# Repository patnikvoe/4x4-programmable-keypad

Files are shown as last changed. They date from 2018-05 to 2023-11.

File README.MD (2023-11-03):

# 4x4 Programmable Keyboard
This project allows you to make a 4x4 programmable keypad. Its similar to standalone numpads, however you can programm each key individually to press one key, key combinations or even complex macros.

## Materials needed:
* 6 mm x 6 mm Tacticle Button (16x)
* 51k Resistor 0603 (16x)
* USB Micro Cable (1x)
* Sparkfun Pro Micro (5V or 3.3V shouldn't really matter) (1x)
* PCB milled with eagle files provided or perfboard + wiring cables
* 3D Printed Enclosure for looks (1x)
* screws depending on your enclosure design 

## Files
All files are stored in there respective folder. Code contains the C++ code for the Sparkfun Pro Micro. Eagle contains the Schematic and Board Files for the ECAD software "Autodesk Eagle".
### Code
The code was written and uploaded using the [hackable texteditor Atom](https://atom.io/) and the extentions [PlatformIO](https://platformio.org/platformio-ide), which are both available for Windows, Linux and macOS.

If you want to use the Arduino IDE, you need to perform two little changes.
Delete the following line or comment it out in the file `code/src/4x4-programmable-keypad.cpp` (Line 7).
```cpp
#include <Arduino.h>
```
Change the File name to `code/src/4x4-programmable-keypad.ino`.

### Quick start in programming your keys
Check the [Arduino Reference](https://www.arduino.cc/reference/en/language/functions/usb/keyboard/) for more detailed information.
#### Keyboard.press(), Keyboard.release(), Keyboard.releaseAll()
Press and release a single keys
```cpp
Keyboard.press(ALT);    // press the left ALT key
delay(50);              // Delays for 50 ms, you might be able to go lower, but 50 is a good starting point
Keyboard.release(ALT);  // Releases the left ALT key again; Alternatively Keyboard.releaseAll()
delay(200);             // Delay for 200 ms so it doesn't get run twice
```
Press and release a key combination
```cpp
Keyboard.press(STRG);   // press the left CTRL/STRG key
Keyboard.press('c');    // press the "c" key
delay(50);
Keyboard.releaseAll();  // release all keys
delay(200);
```
Press and release in a loop to repeat a set number of times
```cpp
for (int i=0;i<10;++i){   // repeat the key combination 10 times
  Keyboard.press(STRG);   // press the left CTRL/STRG key
  Keyboard.press('w');    // press 'w'
  delay(50);              // Delays for 50 ms, you might be able to go lower, but 50 is a good starting point
  Keyboard.release(ALT);  // Releases the left ALT key again; Alternatively Keyboard.releaseAll()
  delay(200);             // Delay for 200 ms so it doesn't get run twice
}
```
#### Keyboard.print(), Keyboard.println()
You can also send strings to your computer. For this you can use the following commands.
```cpp
Keyboard.print('My 4x4 Programmable Keypad ');
delay(50);
Keyboard.print('is awesome.');
delay(200);                     // Delay for 200 ms so it doesn't get run twice
```
Returns:
```
My 4x4 Programmable Keypad is awesome.
```
If you want to have a line break at the end of the line you can use println.
```cpp
Keyboard.println('My 4x4 Programmable Keypad ');
delay(50);
Keyboard.println('is awesome.');
delay(200);                     // Delay for 200 ms so it doesn't get run twice
```
Returns:
```
My 4x4 Programmable Keypad
is awesome.
```

### Eagle Files
Eagle Files were created in Version `9.0.1` of Autodesk Eagle. Newer versions should open it without problems, older versions might run into problems.

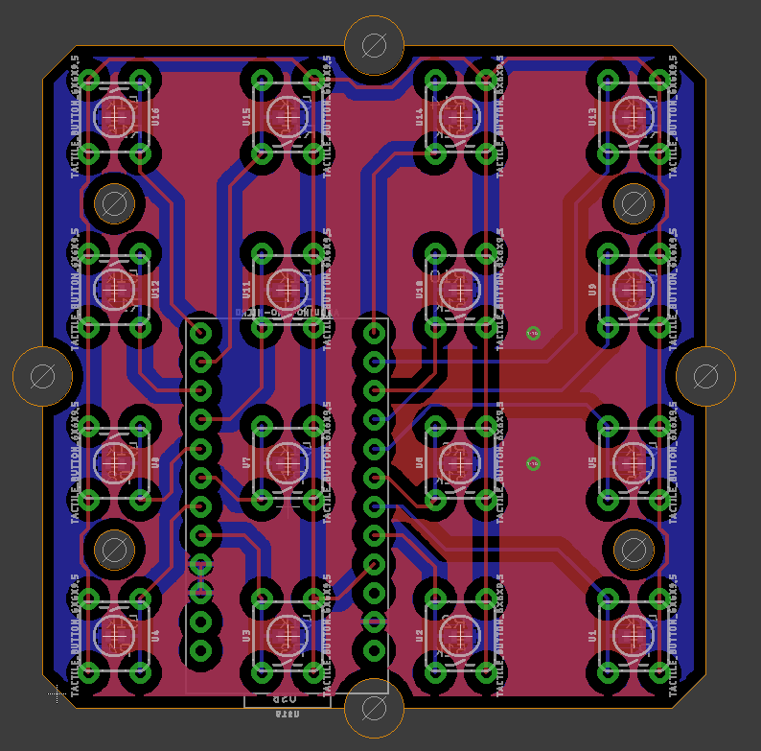
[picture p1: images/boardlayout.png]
Boardlayout


The folder `eagle/gerber-makerspace` contains the CAM files for the [UnternehmerTUM MakerSpace in Garching](https://www.maker-space.de). In case you have your own PCB mill or want to order some, you need to generate your own gerber files.

You might be able to get rid of the resistors, if you change all `pinMode` from `INPUT` to `INPUT_PULLUP` in the file `code/src/4x4-programmable-keypad.cpp`. **I have  not tested this, so try this at your own risk.**
```cpp
pinMode(key[0][0], INPUT);
```
to
```cpp
pinMode(key[0][0], INPUT_PULLUP);
```
You might also need to change the if-Statements from checking `HIGH` to `LOW`:
```cpp
if (digitalRead(key[0][0]) == HIGH)
```
to
```cpp
if (digitalRead(key[0][0]) == LOW)
```

### Enclosure
`Work in progress`

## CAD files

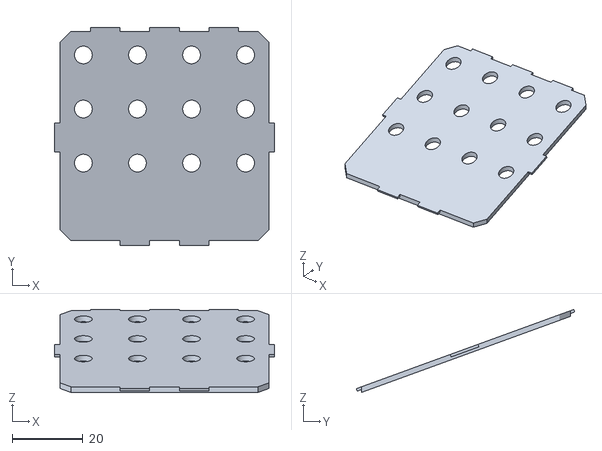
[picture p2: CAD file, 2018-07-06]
enclosure/bottom.stl
62.0 x 61.6 x 23.4

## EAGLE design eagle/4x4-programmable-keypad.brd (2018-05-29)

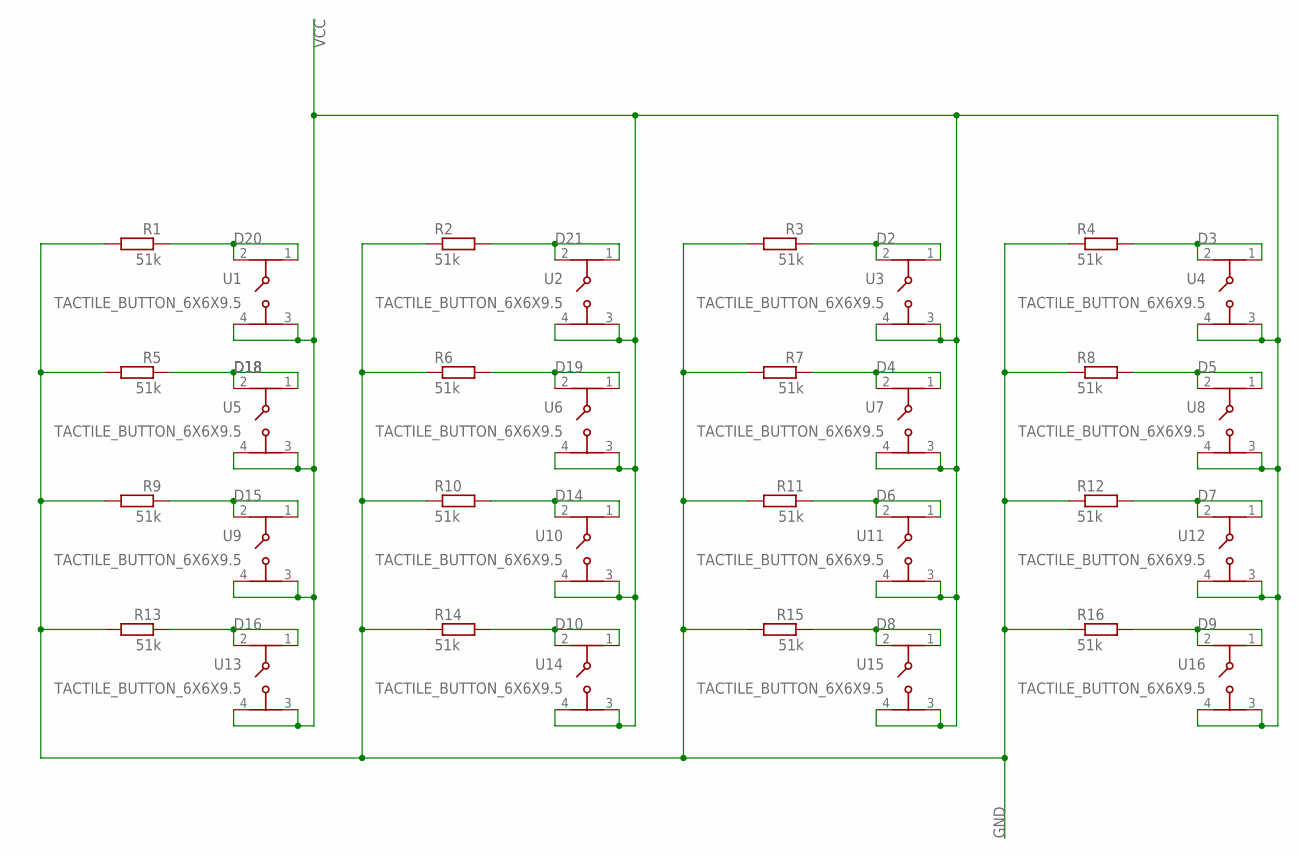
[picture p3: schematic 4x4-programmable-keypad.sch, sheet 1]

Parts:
R1, R2, R3, R4, R5, R6, R7, R8, R9, R10, R11, R12, R13, R14, R15, R16: 51k; R0603
U1, U2, U3, U4, U5, U6, U7, U8, U9, U10, U11, U12, U13, U14, U15, U16: TACTILE_BUTTON_6X6X9.5; TACTILE_SWITCH_PTH_6.0MM

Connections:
D2: R3.1, U3.1, U3.2 (3); also elsewhere on the board
D3: R4.2, U4.1, U4.2 (3); also elsewhere on the board
D4: R7.1, U7.1, U7.2 (3); also elsewhere on the board
D5: R8.2, U8.1, U8.2 (3); also elsewhere on the board
D6: R11.1, U11.1, U11.2 (3); also elsewhere on the board
D7: R12.2, U12.1, U12.2 (3); also elsewhere on the board
D8: R15.1, U15.1, U15.2 (3); also elsewhere on the board
D9: R16.2, U16.1, U16.2 (3); also elsewhere on the board
D10: R14.2, U14.1, U14.2 (3); also elsewhere on the board
D14: R10.2, U10.1, U10.2 (3); also elsewhere on the board
D15: R9.1, U9.1, U9.2 (3); also elsewhere on the board
D16: R13.1, U13.1, U13.2 (3); also elsewhere on the board
D18: R5.1, U5.1, U5.2 (3); also elsewhere on the board
D19: R6.2, U6.1, U6.2 (3); also elsewhere on the board
D20: R1.1, U1.1, U1.2 (3); also elsewhere on the board
D21: R2.2, U2.1, U2.2 (3); also elsewhere on the board
GND: R1.2, R2.1, R3.2, R4.1, R5.2, R6.1, R7.2, R8.1, R9.2, R10.1, R11.2, R12.1, R13.2, R14.1, R15.2, R16.1; also elsewhere on the board
VCC: U1.3 (2), U1.4, U2.3 (2), U2.4, U3.3 (2), U3.4, U4.3 (2), U4.4, U5.3 (2), U5.4, U6.3 (2), U6.4, U7.3 (2), U7.4, U8.3 (2), U8.4, U9.3 (2), U9.4, U10.3 (2), U10.4, U11.3 (2), U11.4, U12.3 (2), U12.4, U13.3 (2), U13.4, U14.3 (2), U14.4, U15.3 (2), U15.4, U16.3 (2), U16.4; also elsewhere on the board

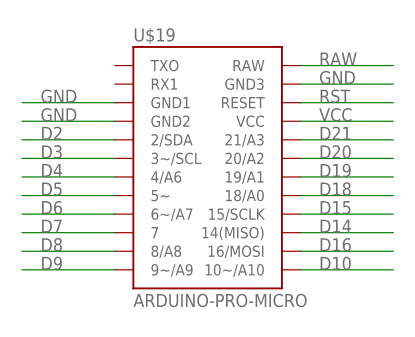
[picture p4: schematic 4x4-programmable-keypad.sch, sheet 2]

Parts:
U$19: ARDUINO-PRO-MICRO; SPARKFUN_PRO_MICRO

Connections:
D2: U$19.2/SDA; also elsewhere on the board
D3: U$19.3~/SCL; also elsewhere on the board
D4: U$19.4/A6; also elsewhere on the board
D5: U$19.5~; also elsewhere on the board
D6: U$19.6~/A7; also elsewhere on the board
D7: U$19.7; also elsewhere on the board
D8: U$19.8/A8; also elsewhere on the board
D9: U$19.9~/A9; also elsewhere on the board
D10: U$19.10~/A10; also elsewhere on the board
D14: U$19.14/MISO (14(MISO)); also elsewhere on the board
D15: U$19.15/SCLK; also elsewhere on the board
D16: U$19.16/MOSI; also elsewhere on the board
D18: U$19.18/A0; also elsewhere on the board
D19: U$19.19/A1; also elsewhere on the board
D20: U$19.20/A2; also elsewhere on the board
D21: U$19.21/A3; also elsewhere on the board
GND: U$19.GND1, U$19.GND2, U$19.GND3; also elsewhere on the board
RAW: U$19.RAW
RST: U$19.RST (RESET)
VCC: U$19.VCC; also elsewhere on the board

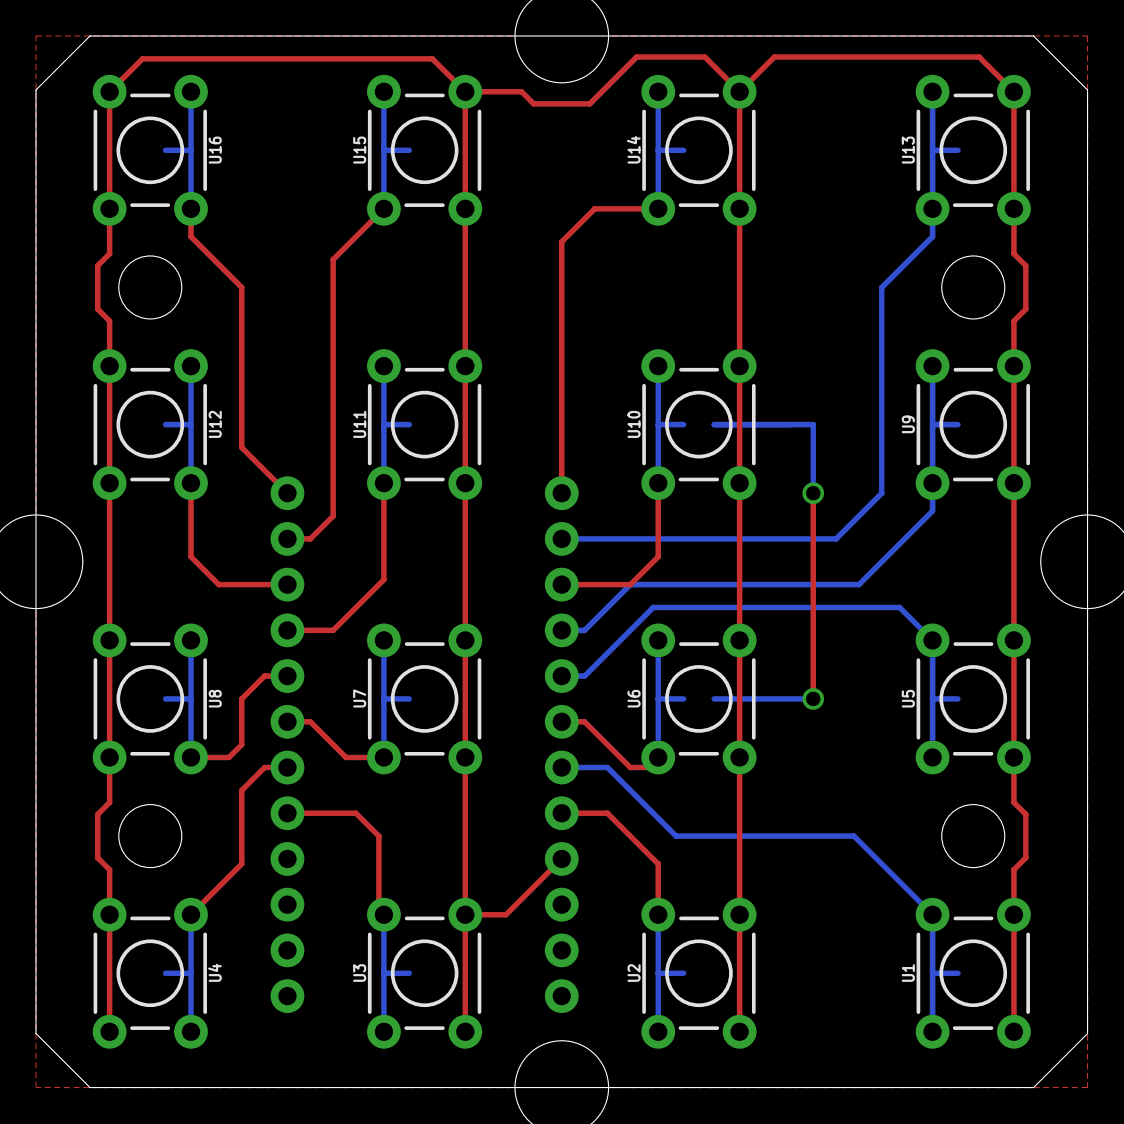
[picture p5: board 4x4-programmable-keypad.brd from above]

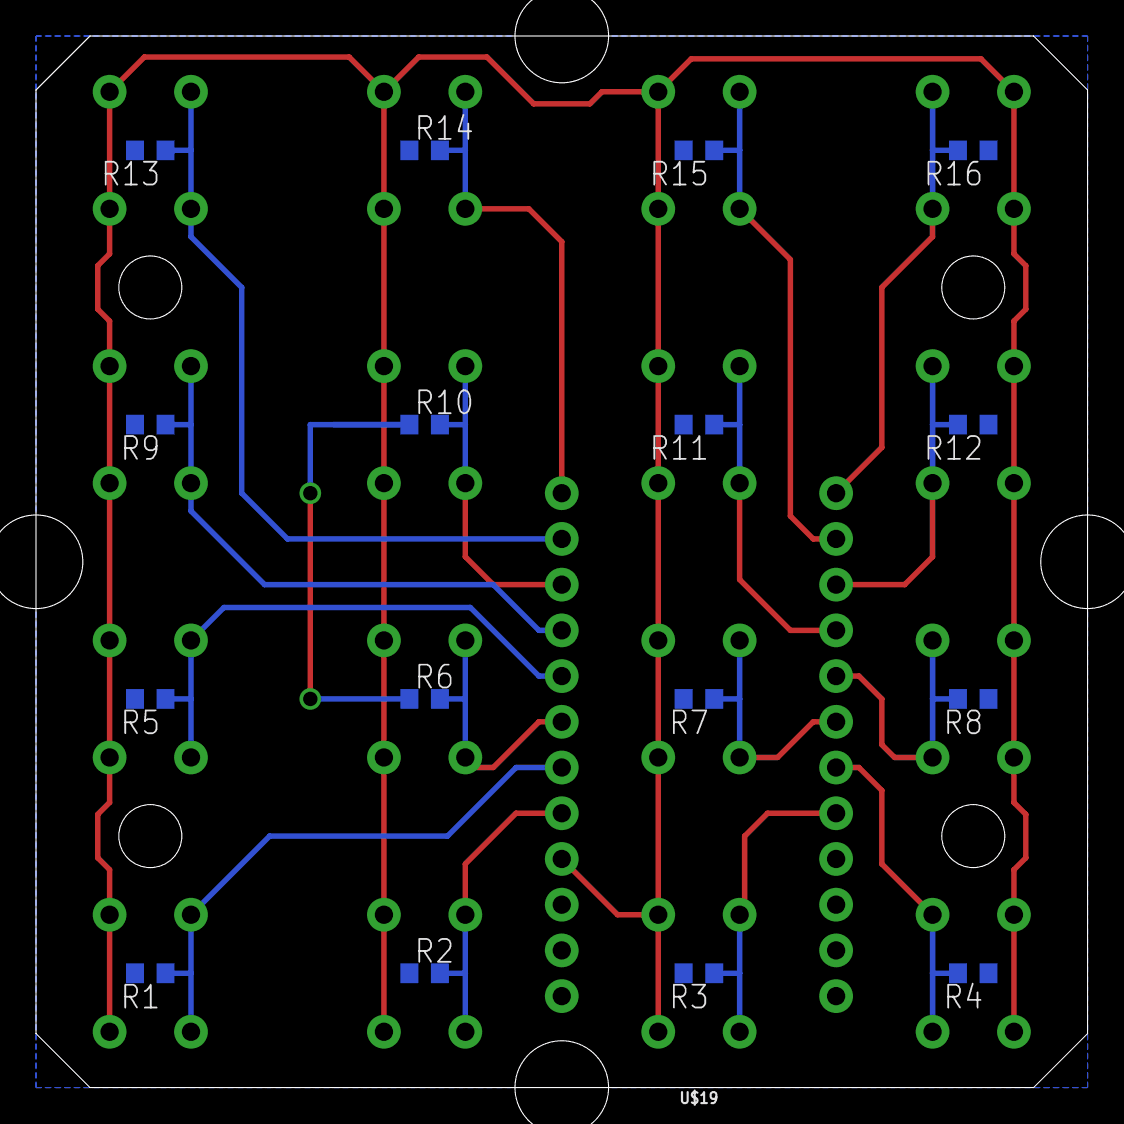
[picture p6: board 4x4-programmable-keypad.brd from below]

Board: 2 copper layers, 58.4 x 58.4 mm, 33 parts (17 on the bottom side), 18 nets.

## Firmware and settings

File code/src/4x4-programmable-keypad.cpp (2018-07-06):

/*
 * Blink
 * Turns on an LED on for one second,
 * then off for one second, repeatedly.
 */

#include "Keyboard.h"
#include <Arduino.h>

// Define Button pins
int key[4][4];

// define keys
char WINDOWS = KEY_LEFT_GUI;
// char CTRL = KEY_LEFT_CTRL;
char STRG = KEY_LEFT_CTRL;
char ALT = KEY_LEFT_ALT;
char ALTGR = KEY_RIGHT_ALT;
char SHIFT = KEY_LEFT_SHIFT;
char ENTER = KEY_RETURN;
char TAB = KEY_TAB;
char BACKSPACE = KEY_BACKSPACE;
char ESC = KEY_ESC;
// char DELETE = KEY_DELETE;
char ENTF = KEY_DELETE;
// char INSERT = KEY_INSERT;
char EINFG = KEY_INSERT;
// char END = KEY_END;
char ENDE = KEY_END;
// char HOME = KEY_HOME;
char POS1 = KEY_HOME;
// F-keys
/*
char F1 = KEY_F1;
char F2 = KEY_F2;
char F3 = KEY_F3;
char F4 = KEY_F4;
char F5 = KEY_F5;
char F6 = KEY_F6;
char F7 = KEY_F7;
char F8 = KEY_F8;
char F9 = KEY_F9;
char F10 = KEY_F10;
char F11 = KEY_F11;
char F12 = KEY_F12;
*/
// Arrowkeys
// char LEFT = KEY_LEFT_ARROW;
char LINKS = KEY_LEFT_ARROW;
// char RIGHT = KEY_RIGHT_ARROW;
char RECHTS = KEY_RIGHT_ARROW;
// char UP = KEY_UP_ARROW;
char OBEN = KEY_UP_ARROW;
// char DOWN = KEY_DOWN_ARROW;
char UNTEN = KEY_DOWN_ARROW;
// Page keys
// char PAGEUP = KEY_PAGE_UP;
char BILDAUF = KEY_PAGE_UP;
// char PAGEDOWN = KEY_PAGE_DOWN;
char BILDAB = KEY_PAGE_DOWN;

void setup() {
  // initialize control over the keyboard:

  Serial.begin(115200);
  Keyboard.begin();

  key[0][0] = 20;
  key[1][0] = 21;
  key[2][0] = 2;
  key[3][0] = 3;
  key[0][1] = 18;
  key[1][1] = 19;
  key[2][1] = 4;
  key[3][1] = 5;
  key[0][2] = 15;
  key[1][2] = 14;
  key[2][2] = 6;
  key[3][2] = 7;
  key[0][3] = 16;
  key[1][3] = 10;
  key[2][3] = 8;
  key[3][3] = 9;

  // make pin 2 an input and turn on the pull-up resistor so it goes high unless
  // connected to ground:
  pinMode(key[0][0], INPUT);
  pinMode(key[1][0], INPUT);
  pinMode(key[2][0], INPUT);
  pinMode(key[3][0], INPUT);
  pinMode(key[0][1], INPUT);
  pinMode(key[1][1], INPUT);
  pinMode(key[2][1], INPUT);
  pinMode(key[3][1], INPUT);
  pinMode(key[0][2], INPUT);
  pinMode(key[1][2], INPUT);
  pinMode(key[2][2], INPUT);
  pinMode(key[3][2], INPUT);
  pinMode(key[0][3], INPUT);
  pinMode(key[1][3], INPUT);
  pinMode(key[2][3], INPUT);
  pinMode(key[3][3], INPUT);
}

void loop() {

  if (digitalRead(key[0][0]) == HIGH) {
    delay(50);
    Keyboard.press(STRG);
    Keyboard.press('l');
    delay(50);
    Keyboard.releaseAll();
    delay(100);

    Keyboard.press(STRG);
    Keyboard.press('c');
    delay(50);
    Keyboard.releaseAll();
    delay(100);
  } else if (digitalRead(key[1][0]) == HIGH) {
    Keyboard.press(STRG);
    Keyboard.press('l');
    delay(50);
    Keyboard.releaseAll();
    delay(100);

    Keyboard.press(STRG);
    Keyboard.press('b');
    delay(50);
    Keyboard.releaseAll();
    delay(500);
  } else if (digitalRead(key[2][0]) == HIGH) {
    Keyboard.press(STRG);
    Keyboard.press('l');
    delay(50);
    Keyboard.releaseAll();
    delay(100);

    Keyboard.press(STRG);
    Keyboard.press('k');
    delay(50);
    Keyboard.releaseAll();
    delay(500);
  } else if (digitalRead(key[3][0]) == HIGH) {

  } else if (digitalRead(key[0][1]) == HIGH) {
    Keyboard.press(STRG);
    Keyboard.press('a');
    delay(50);
    Keyboard.releaseAll();
    delay(500);
  } else if (digitalRead(key[1][1]) == HIGH) {
    Keyboard.press(STRG);
    Keyboard.press('x');
    delay(50);
    Keyboard.releaseAll();
    delay(500);
  } else if (digitalRead(key[2][1]) == HIGH) {
    Keyboard.press(STRG);
    Keyboard.press('c');
    delay(50);
    Keyboard.releaseAll();
    delay(500);
  } else if (digitalRead(key[3][1]) == HIGH) {
    Keyboard.press(STRG);
    Keyboard.press('v');
    delay(50);
    Keyboard.releaseAll();
    delay(500);
  } else if (digitalRead(key[0][2]) == HIGH) {

  } else if (digitalRead(key[1][2]) == HIGH) {

  } else if (digitalRead(key[2][2]) == HIGH) {

  } else if (digitalRead(key[3][2]) == HIGH) {

  } else if (digitalRead(key[0][3]) == HIGH) {

  } else if (digitalRead(key[1][3]) == HIGH) {

  } else if (digitalRead(key[2][3]) == HIGH) {

  } else if (digitalRead(key[3][3]) == HIGH) {
  }
}

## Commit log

2018-05-25 Eagle files update
    [4x4-programmable-keypad.brd, 4x4-programmable-keypad.sch]
2018-05-25 Gerber Files for maker-space.de
2018-05-25 Arduino Code 0.1
2018-05-25 folder for eagle files created, eagle files moved
    [4x4-programmable-keypad.brd, 4x4-programmable-keypad.sch]
2018-05-29 Update board and schematic
    [4x4-programmable-keypad.brd, 4x4-programmable-keypad.sch]
2018-05-29 New CAM Export
    [gerber_job.gbrjob]
2018-06-05 Gerber updated
2018-06-06 Keyboard.println info text
2018-06-06 boardlayout inserted picture
